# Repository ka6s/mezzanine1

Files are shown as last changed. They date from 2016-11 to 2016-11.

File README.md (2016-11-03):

Mezzanine1

This is a small 5V power supply that can be added to the existing RP_ADAPTER.

It uses Anderson Power Poles to receive 12V. These being modular -they can be connected to the 
existing power connection of the rp_adapter.  This was created to power the Raspberry Pi.

There are two USB connectors and a 13.8V fan connection available.

This is a total rip-off of the LPU 5V section of provided by OpenHPSDR and all credit goes to them,
all blame for layout issues goes to me.

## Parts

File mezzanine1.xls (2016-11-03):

Id | Mouser Part number | Designator | Package | Quantity | Designation | Supplier and ref
2 | 80-C1206C104K5R | C1,C4 | C_1206_HandSoldering | 2 | 0.1uF
3 | 81-GRM422X105K50L (http://www.mouser.com/ProductDetail/Murata-Electronics/GRM32RR71H105KA01L/) | C2,C5 | C_1210_HandSoldering | 2 | 1uF
4 | 81-GRM422R106K16L (http://www.mouser.com/ProductDetail/Murata-Electronics/GRM32DR61C106KA01L/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) | C3,C6,C7 | C_1210_HandSoldering | 3 | 100uF
6 | 538-22-23-2031 | P1 | Pin_Header_Straight_1x03 | 1 | CONN_01X03
7 | 490-UJ2-AH-4-TH | P2,P3 | USB_A | 2 | USB_A
8 | 71-CP00102R200JE663 | R1 | RES_10W | 1 | 2.2
 | 879-1327 (http://www.mouser.com/ProductDetail/Anderson-Power-Products/1327/?qs=sGAEpiMZZMuP%2FQeRSdvksHAvir4742Xo) | U1 | POWER_POLE-Red | 1
9 | 879-1327G6 (http://www.mouser.com/ProductDetail/Anderson-Power-Products/1327G6/) | U1 | POWER_POLE-Black | 1
10 | 879-1335G1 | U1 | STR POWER_POLE- Metal | 2 | PwrPole
11 | 512-KA278R05CTU | U2 | TO-220_4pin_vertical | 1 | KA278R05

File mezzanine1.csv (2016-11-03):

Id | Designator | Package | Quantity | Designation | Supplier and ref
1 | REF**,REF** | 1pin | 2 | 1pin
2 | C1,C4 | C_1206_HandSoldering | 2 | 0.1uF
3 | C2 | C_1210_HandSoldering | 1 | 1uF
4 | C3,C6,C7 | C_1210_HandSoldering | 3 | 100uF
5 | C5 | C_1206_HandSoldering | 1 | 1uF
6 | P1 | Pin_Header_Straight_1x03 | 1 | CONN_01X03
7 | P2,P3 | USB_A | 2 | USB_A
8 | R1 | RES_10W | 1 | 2.2
9 | U1 | RA_POWER_POLE | 1 | PwrPole
10 | U2 | TO-220_4pin_vertical | 1 | KA278R05

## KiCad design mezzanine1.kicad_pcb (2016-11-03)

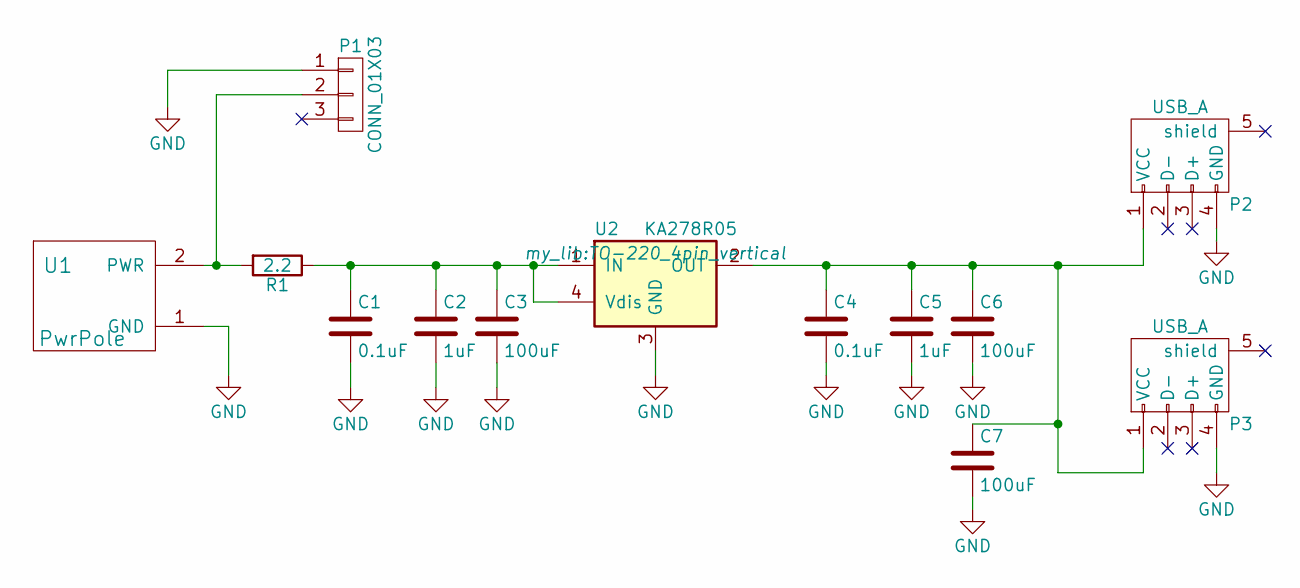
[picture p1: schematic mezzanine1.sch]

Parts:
C1, C4: 0.1uF; C_1206_HandSoldering
C2: 1uF; C_1210_HandSoldering
C3, C6, C7: 100uF; C_1210_HandSoldering
C5: 1uF; C_1206_HandSoldering
P1: CONN_01X03; Pin_Header_Straight_1x03
P2, P3: USB_A
R1: 2.2; RES_10W
U1: PwrPole; RA_POWER_POLE
U2: KA278R05; TO-220_4pin_vertical

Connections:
GND: C1.2, C2.2, C3.2, C4.2, C5.2, C6.2, C7.2, P1.1, P2.4 (GND), P3.4 (GND), U1.1 (GND), U2.3 (GND)
unnamed: C1.1, C2.1, C3.1, R1.1, U2.1 (IN), U2.4 (Vdis)
unnamed: C4.1, C5.1, C6.1, C7.1, P2.1 (VCC), P3.1 (VCC), U2.2 (OUT)
unnamed: P1.2, R1.2, U1.2 (PWR)

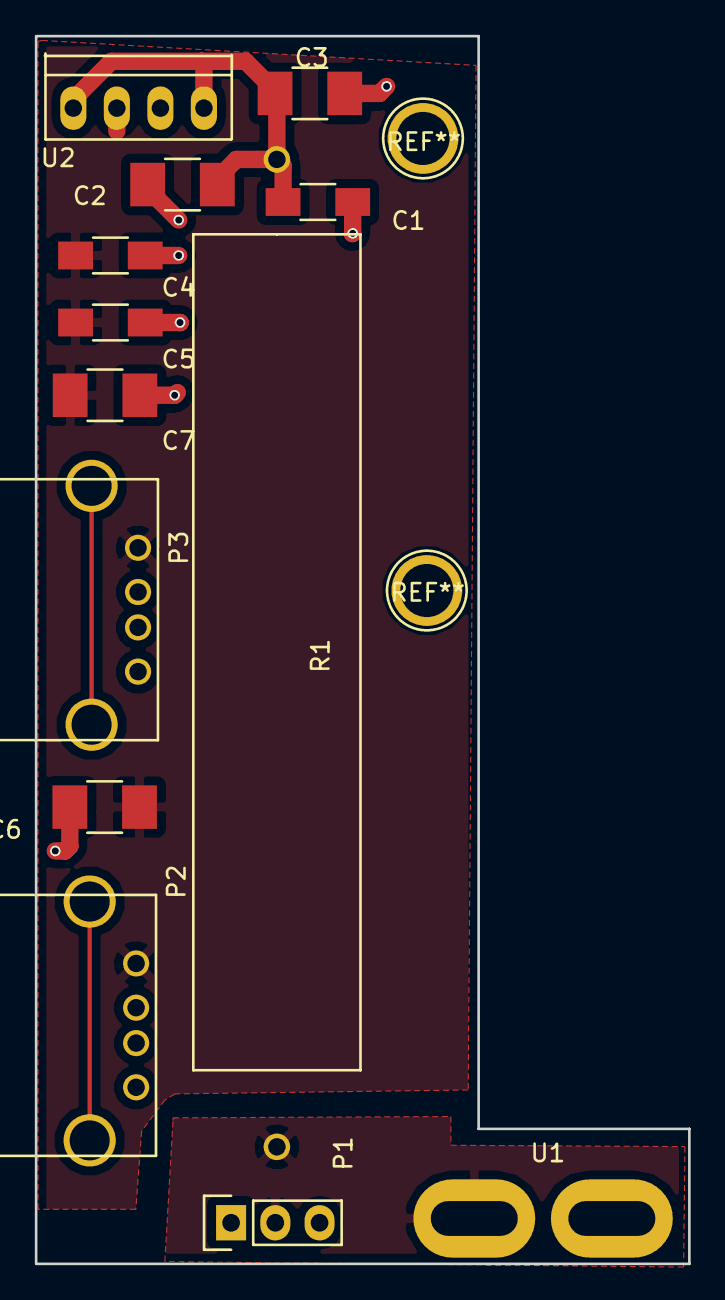
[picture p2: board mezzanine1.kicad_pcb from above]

Board: 2 copper layers, 37.5 x 70.5 mm, 13 parts (0 on the bottom side), 4 nets.
